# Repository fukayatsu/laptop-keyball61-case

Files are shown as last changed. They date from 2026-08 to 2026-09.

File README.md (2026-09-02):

# Keyball61 ラップボード

[Keyball61](https://shirogane-lab.net/)（左右ともトラックボール搭載）を膝上で使うための
3Dプリント製ラップボード。極力2mm厚の平面で構成し、キーボードは付属の
アクリル底板の代わりにプレートへ純正ネジで直接固定する。

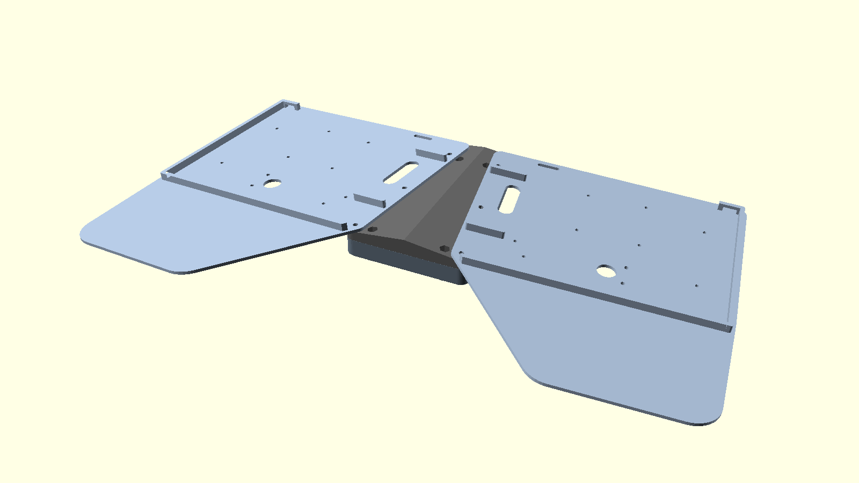
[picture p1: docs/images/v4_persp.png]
組立

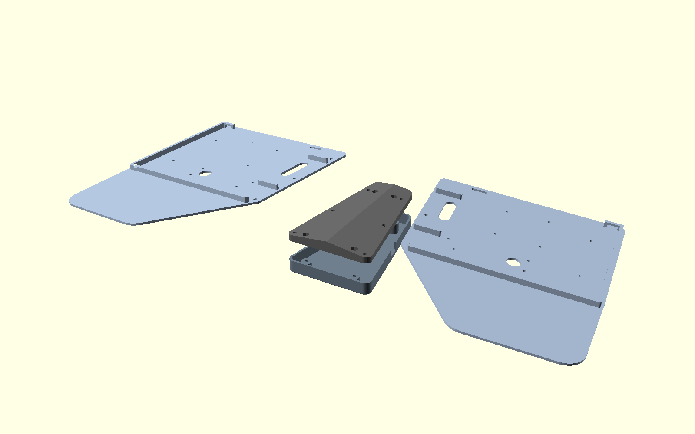
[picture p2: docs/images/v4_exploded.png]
分解


## 構成 (4パーツ + M3×8なべ×6 + M3×8皿×4 + M3ナット×10)

| パーツ | 印刷 | 説明 |
|---|---|---|
| `stl/v4_plate_left/right.stl` | ベタ置き | **一体平面プレート**(2mm): キーボード搭載部+パームレスト+中央張り出し。たわみ抑えのL字リブ(3×5mm)付き |
| `stl/v4_center_spine.stl` | ベタ置き | **切妻テント形の中実スパイン**: 上面=左右7°の切妻(テント角を作る)、底面=フラットで浮く。厚さ5.4〜11mm。底面は下面カバーの蓋を兼ねる |
| `stl/v4_center_cover.stl` | ベタ置き | **下面カバー**(任意): スパイン下の空間(深さ約10mm)を覆う。底2mm+スカート壁、外周はスパインと面一。底面の接地エッジと座ぐり口元は45°面取り(足に当たるため) |

- スプレイ10°・テンティング7°(スパインの形状が作る)・左右間隔は `v4_corner_x = 20`
- 全パーツ**組立の向きのままベタ置き印刷・サポートゼロ**
- **全ネジがボルト+ナット**(セルフタップなし):
  - ジョイント: プレート内縁がスパインに12mm重なり、上からM3×8なべ×3/側→
    スパイン底面の六角ポケットのナット(回り止め・天井は45°テーパーで印刷品質確保)
  - カバー: 下からM3×8皿×4(座ぐり奥の90°皿座=45°テーパーで印刷品質確保)→
    スパイン上面(露出帯)の六角井戸に落としたナット
- キーボードは従来のアクリルと同様、プレートに下から純正ネジで固定
- たわみ抑えリブ: ジェルパッド80×95mm領域(パーム外側の隅)の北縁+外側エッジの
  L字(パッドの位置決めストッパー兼用) + **スパイン接続帯の横リブ×2**(蝶番になる
  帯を曲げに直交する向きで補強)
- ケーブル関連: 外側後方の角に**ベルトループ**(上面のバー下にバンドを通す。
  貫通穴だとバンドが足に当たるため)、親指M2穴の真北に3×15貫通スロット、
  TRRSジャック真東にTRSケーブル通し穴10×33(プラグごと裏へ通しカバーのTRSノッチへ)、
  カバー北縁にUSBノッチ
- 注意: 平面構造なのでプレートは接地ライン(外側エッジ)以外浮く。膝上での使用前提

## 組立

1. スパイン底面の六角ポケット×6にM3ナットを差し込む
2. プレートをスパインの屋根フランジに重ね、上からM3×8なべ×3/側で締結
3. キーボードをプレートに載せ、下から純正ネジで固定(アクリル底板と同じ要領)。
   ボールケースも従来通り
4. (任意) スパイン上面の六角井戸×4にナットを落とし、カバーを下からM3×8皿×4で固定。
   ケーブル・Touch IDモジュール等はカバー内へ(バッテリー123mmは直置き不可)。
   Touch IDの固定は下の「Touch IDモジュール取付」を参照
5. ジェルパッドをリブに突き当てて貼る

## Touch IDモジュール取付 (任意)

カバー内に入れるTouch IDモジュールを固定する小物2点。

| パーツ | 印刷 | 説明 |
|---|---|---|
| `stl/touchid_plate.stl` | 底面をベッドに置く | **取付プレート**(15.6×16.0×1.05mm): 板厚0.9mm+天面中央にφ3×0.15mmのボス(モジュールの当たり面)。南辺にケーブル逃げの切欠き |
| `stl/touchid_foot.stl` | ベタ置き | **十字フット**(15.1×14.4×2.0mm): プレート裏の2mmスペーサ。プレートに接着する |

- 固定は**超低頭ネジ×4**。頭(φ2.72実測)がプレート裏に露出する構成なので、
  通し穴は「軸φ1.8が通り、かつ頭が座る」φ2.5にしてある。印刷で穴が細く出る前提の
  寸法で、頭が抜けるようなら `touchid_hole_d` を下げる
- **フットが十字なのはネジ頭を逃げるため**。単純な帯だと短辺6mmで倒れるので直交
  バーを足して支持スパンを 6.0 → 14.4mm に広げた。バー幅を決めているのはネジ穴
  ではなく裏に露出する頭で、穴中心から
  `touchid_head_d/2 + touchid_foot_head_clr` = 2.0mm を空けている
- 一体で出力しようとすると、天面を伏せれば中央ボス(0.15mm)だけが1層目になって
  プレート全面が宙に浮き、フット側を下にすればプレート四隅(ネジ座面)が
  無支持の張り出しになる。**2部品に分けて接着するのが正解**
- プレート天面のボスは0.15mmしかないので**積層0.15mm以下**で印刷すること

寸法は `scad/touchid/touchid_params.scad` に集約してある。

## ビルド

```sh
make            # 全STL生成 (要 OpenSCAD: brew install --cask openscad)
make v4         # ラップボード本体のみ
make touchid    # Touch ID取付部品のみ
make check      # 設計検証 (v4は要 pip install trimesh numpy)
make images     # ドキュメント画像の再生成
```

パラメータは `scad/params.scad`(共通)と `scad/v4/v4_params.scad`。
キーボード外形は公式アクリルDXFから `scripts/extract_outline.py` で生成した実寸
(`scad/keyball61_outline.scad`, ポイント単位 0.353407mm/unit)。

`make check` は2本の検証を回す。設計変更のたびに必ず実行すること。

- `scripts/verify_v4.py` (`make check-v4`): 単一ボディ/平面性/ネジ軸の素通し/
  ナット位置の空洞/印刷オーバーハング/部品間干渉
- `scripts/verify_touchid.py` (`make check-touchid`): ネジ穴が公称径で貫通しているか/
  ネジ頭の座面幅/フットがネジ頭を逃げているか/フットがプレート外形からはみ出して
  いないか/ベタ置きできる平面か。依存なし(標準ライブラリのみ)

`scad/touchid/` は本体(`scad/v4/`)とは独立していて、`scad/params.scad` の
`$fn` だけを共有する。

## 履歴

- v1(可動キャリッジ式)・v2(固定式の楔+ブリッジ+ブレース)・v3(中空モジュール5分割)は
  git履歴を参照。v4は前作ラップボードの平面構造方式を採用したもの

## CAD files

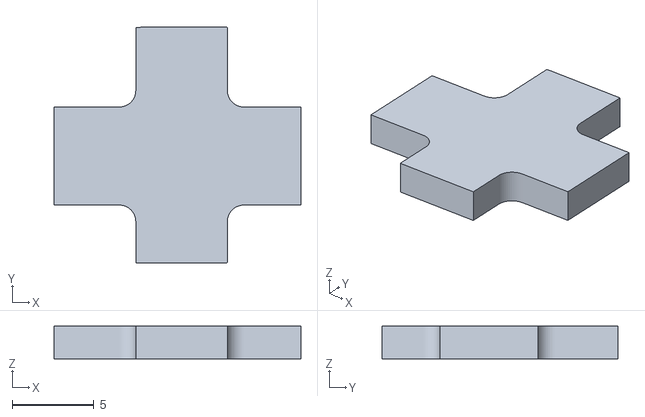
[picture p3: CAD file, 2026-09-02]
stl/touchid_foot.stl
15.1 x 14.4 x 2.00

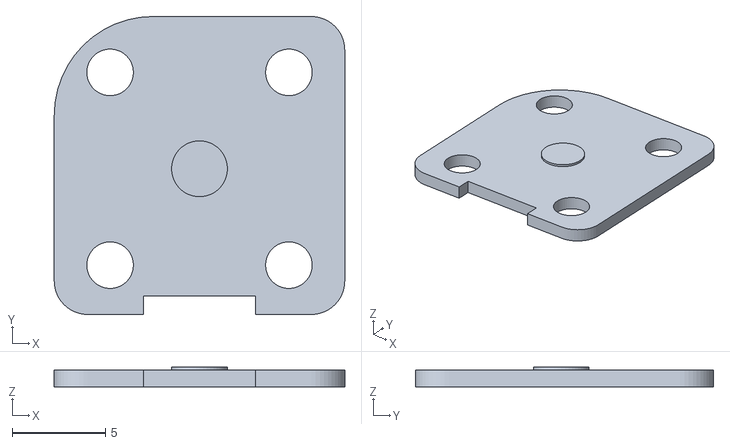
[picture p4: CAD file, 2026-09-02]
stl/touchid_plate.stl
15.6 x 16.0 x 1.05

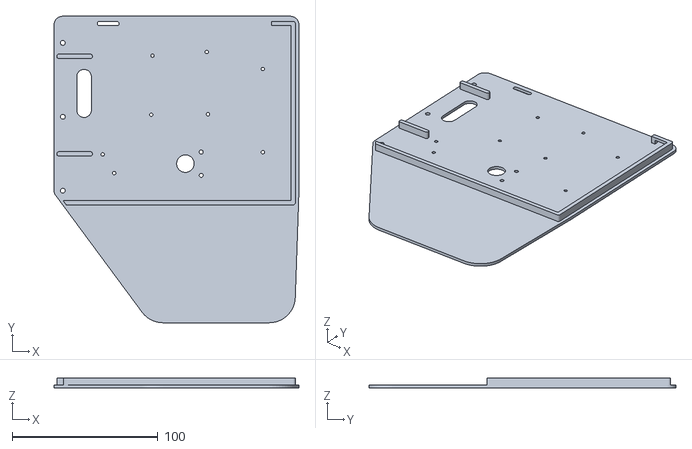
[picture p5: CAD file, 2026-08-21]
stl/v4_plate_right.stl
168.2 x 210.5 x 7.00

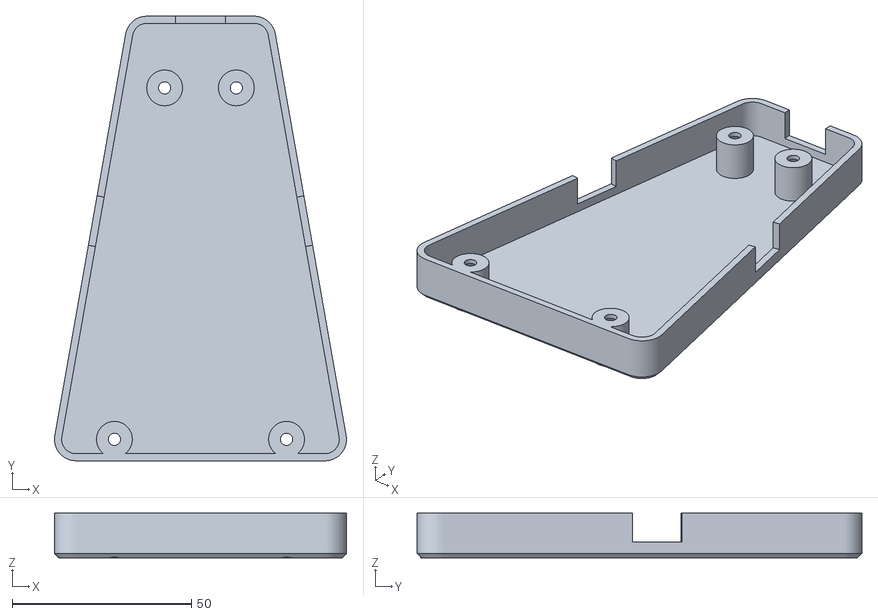
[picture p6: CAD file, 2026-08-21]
stl/v4_center_cover.stl
81.4 x 124.0 x 12.4

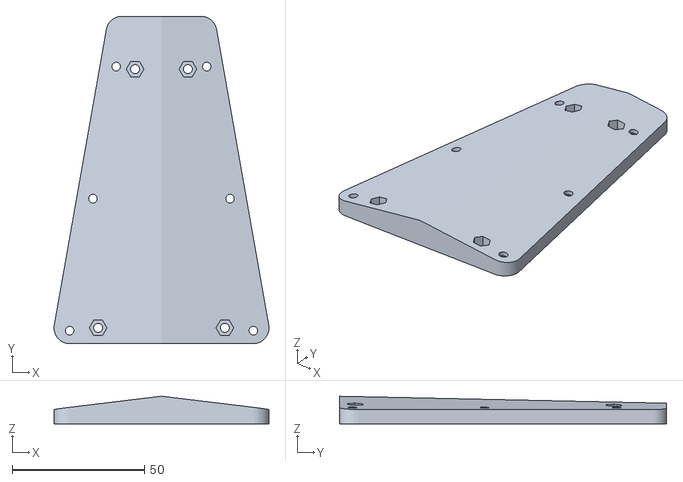
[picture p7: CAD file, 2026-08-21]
stl/v4_center_spine.stl
81.4 x 124.0 x 10.4

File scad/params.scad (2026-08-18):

// ============================================================
// Keyball61 ラップボード 共通パラメータ (v4で使用する項目のみ)
// 座標系: X+ = 右(東), Y+ = 奥(北), Z+ = 上
// 組立座標系(グローバル): 中心 x=0, 手前が y小
// 旧v2(固定式楔)・v3(中空モジュール)のパラメータはgit履歴を参照
// ============================================================

clr = 0.35;           // はめあいクリアランス(片側)

// ---------- 全体レイアウト ----------
splay        = 10;    // ハの字角(固定)。変更したら全パーツ再印刷
tent_angle   = 7;     // テンティング角(内側が高い)
kb_corner_x  = 45;    // キーボードブロック後内側コーナーの中心からの距離
                      // (v4は v4_corner_x = kb_corner_x - 25 を使用)
kb_corner_y  = 238;   // 同コーナーのY

// ---------- キーボード搭載部 ----------
kb_wall      = 6;     // アクリル外形の周囲マージン(外形の配置オフセット)
wedge_t0     = 6;     // 楔面の基準肉厚(lib.scadの傾斜面定義で使用)
plate_t      = 2;     // 取付プレート厚(=アクリル板厚。純正ネジ長がそのまま使える)
pocket_depth = 4.6;   // lib.scadの座面高さ定義で使用

// ---------- パームレスト ----------
palm_w       = 108;   // パームレスト幅
palm_x0      = 2.5;   // パームの外側エッジ位置(kbフレームx)
palm_d       = 88;    // 同奥行き
palm_overlap = 3;     // キーボードブロックへの食い込み
palm_r       = 18;    // 角R

// ---------- 穴径 ----------
ball_hole_d  = 12;    // ボール取出し穴(アクリルは11.3)
m2_hole_d  = 2.4;     // M2クリアランス(プレート側)
bc_hole_d  = 2.8;     // ボールケースネジ(プレート側, アクリルは2.36)

// M3 (ジョイント・カバー固定)
m3_hole_d  = 3.4;
m3_cs_d    = 6.8;     // 皿ざぐり径
m3_nut_af  = 5.8;     // 六角ナットポケット対辺(M3ナット5.5+0.3)
m3_nut_t   = 2.9;     // 同深さ

$fn = 48;

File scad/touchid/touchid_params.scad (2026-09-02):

// ============================================================
// Touch ID モジュール取付プレート + 十字フット のパラメータ
// 座標系: 上から見た形 / 原点=外形バウンディングボックスの南西角 / +Z=天面側
// 寸法はモジュール実物に合わせた実測値
// ============================================================

// ---------- プレート外形 ----------
touchid_plate_w = 15.6;   // 幅
touchid_plate_d = 16.0;   // 奥行き
touchid_plate_t = 0.9;    // 板厚(ネジ穴が貫通する厚み)
touchid_r_corner = 1.8;   // 南西・南東・北東の角R
touchid_r_nw     = 5.3;   // 北西の角R(ここだけ大きい)

// 南辺の切欠き(ケーブル逃げ)
touchid_notch_x  = [4.8, 10.8];
touchid_notch_d  = 1.0;

// ---------- ネジ穴 ----------
// 超低頭ネジ。軸φ1.8が通り、頭φ2.72がプレート裏に露出する
touchid_hole_d = 2.5;     // 通し穴。φ2.7では頭が座らず抜ける
touchid_head_d = 2.72;    // 頭径(実測)
touchid_hole_x = [3.0, 12.6];
touchid_hole_y = [2.65, 13.0];

// ---------- 天面のボス(モジュールの当たり面) ----------
touchid_boss_d = 3.0;
touchid_boss_h = 0.15;

// ---------- 十字フット ----------
touchid_foot_h        = 2.0;   // プレート裏に噛ませるスペーサ厚
touchid_foot_head_clr = 0.64;  // ネジ頭の外周からフットまでの逃げ
touchid_foot_fillet   = 1.0;   // 十字の内隅R(応力集中よけ)
touchid_foot_edge_clr = 0.3;   // Y方向バー端をプレート外形から控える量
touchid_foot_xbar     = [[0, 15.1], 3.0];  // [Xの範囲, ネジ列中心からの半幅]

// ---------- 導出 ----------
touchid_holes = [for (y = touchid_hole_y, x = touchid_hole_x) [x, y]];
touchid_hole_cx = (touchid_hole_x[0] + touchid_hole_x[1]) / 2;
touchid_hole_cy = (touchid_hole_y[0] + touchid_hole_y[1]) / 2;
// 穴中心から確保すべき逃げ半径(ネジ穴ではなく「裏に出る頭」で決まる)
touchid_head_r = touchid_head_d / 2 + touchid_foot_head_clr;

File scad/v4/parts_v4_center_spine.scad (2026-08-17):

include <v4_center_spine.scad>
// 底面(フラット)をベッドに置いて印刷。上面は7°の緩斜面でサポートゼロ
translate([0, 0, -v4_spine_z0]) v4_center_spine();

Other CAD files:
stl/v4_plate_left.stl
scad/v4/v4_center_spine.scad
scad/keyball61_outline.scad
scad/lib.scad
scad/touchid/parts_touchid_foot.scad
scad/touchid/parts_touchid_plate.scad
scad/touchid/touchid_foot.scad
scad/touchid/touchid_plate.scad
scad/v4/parts_v4_center_cover.scad
scad/v4/parts_v4_plate_left.scad
scad/v4/parts_v4_plate_right.scad
scad/v4/v4_assembly.scad
scad/v4/v4_center_cover.scad
scad/v4/v4_params.scad
scad/v4/v4_plate.scad

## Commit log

2026-08-14 固定式ラップボードv2の設計一式を追加
    - サイド2枚(取付面+パームレスト+7°楔+ハの字10°) + 中央ブリッジ + ブレースプレート + Touch IDポッド(バッテリー有無2種)の構成
    - ケースはアクリル底板の置き換え: 純正M2/ボールケースネジで直接固定(ネジ穴下は肉厚2.0mm)
    - 外形は公式DXF(3:1スケール)から実寸抽出(scripts/extract_outline.py)
    - 継手はリブ入り連続タブ(サイド凸/ブリッジ凹)、ブレースで閉断面化。全パーツサポート不要
    - ネジはM3x8皿×14+M3ナット×6に統一(KB固定は純正流用)
    - 旧・可動キャリッジ版は archive/adjustable-v1/ に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
    [assembly.scad, base.scad, brace.scad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]
2026-08-14 DXFスケールを実寸に修正し、H形ブレースを追加
    - 底板DXFのスケール誤りを修正: 3:1ではなくポイント単位(0.353407mm/unit)。
    公式KiCad基板(Right/Ball側)のスペーサー穴8点との相似変換フィット(残差0.002mm)で確定。
    プレート実寸 142.99x113.53mm (PCB Edge.Cuts 142.9x113.5 と一致)。全パーツ再生成
    - TRRSジャック位置を基板から実測 (グローバル ∓72, 181)
    - ブレースをH形に拡大 (155x130x3.5, y=100..230): TRSプラグ/ケーブル降下ゾーン
    (y168-212)を角丸切り欠きで回避しつつカバー面積を拡大。固定 M3x8皿 x3/側
    - パームレスト幅を150mmに戻す (kbブ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
    [brace.scad, brace.stl, bridge.stl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]
2026-08-14 パームレストの親指側をカットし印刷を安定化
    - パーム幅を150→108mm(外側基準 palm_x0=2.5)に絞り、親指側(内側前方)を開放
    - ブレース南帯の座面用に内側エッジ沿いへ幅14mmの支持アームを追加
    (ブリッジ/ブレースとの接合部は不変)
    - アーム〜パーム間はクロージングR22+オープニングR2で滑らかな輪郭に
    - ボールPCB逃げの矩形をプレート外形東端までに制限
    (内壁と継ぎ目帯を貫通してブレース中央帯ネジ座の材料を消していたバグを修正)
    [params.scad, side.scad, side_left.stl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]
2026-08-14 ブレースに親指キー回避の切り欠きを追加
    - 南ネジと中央ネジの間(y=114..147)のエッジを継ぎ目から12mm中央寄りに後退させ、
    キーボードの親指キークラスタの張り出しとの干渉を回避
    - TRS用の深い切り欠き(y=168..212)と中央ネジ(y=154)は維持。ネジ構成変更なし
    - 調整パラメータ: brace_thumb_y0/y1, brace_thumb_inset
    [brace.scad, brace.stl, params.scad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]
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2026-08-14 前方の逃げ範囲を調整し、ボールケースネジの座を確保
    - 実機のトラックボール部がプレートからはみ出すため、前方の縁の
    4mm掘り下げをボール周辺(プレートx=40)から東側に拡大
    (全幅までは不要のためボール周辺のみ。小指側の外周は元の高さ)
    - 外形線ぎわのボールケースネジ周囲Ø14は取付面レベルの座として残し、
    座ぐりの欠けを解消(掘り下げから保護しつつ取付面と同じ高さに彫る)
    [side.scad, side_left.stl, side_right.stl]
2026-08-15 ポッドのケーブル経路を整理
    - ベイ北壁にケーブル引き出しスリットを追加(幅12→15に拡大)
    - TRSケーブルギャラリーを廃止(スリットから北へ直接引き出す方式に)。
    ポッドは 64x94x8 / 64x132x11(電池版) に小型化
    - 充電ポート開口(南面)が壁を貫通していなかったのを修正し、
    さらに上開きのU字スロット化(庇0.5mmのブリッジを排除)。tid_port_h 廃止
    - トレイはブリッジ・サポート完全不要の形状に
    [params.scad, touchid_pod.scad, touchid_pod.stl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]
2026-08-16 キーボード固定をベッド直接印刷のマウントプレート方式に変更
    - 新パーツ mount_plate 左右各1 (143x114x2, アクリル底板相当):
    ベッドに平置き印刷して穴精度・平面・2mm厚を確保。キーボードとは
    純正M2/ボールケースネジで固定(楔内部の座ぐり奥の2mm薄肉は
    印刷精度が出ず固定に失敗したため=実印刷での知見)
    - サイド: ポケットを2mm深く(4.6)してプレートを収容。M2/BC位置は
    精度不要のΦ8貫通穴(ネジ頭逃げ+下からのドライバーアクセス)に置換
    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
    [brace.stl, bridge.stl, mount_plate.scad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]
2026-08-17 モジュラー構造v3(中空5分割・垂直ジョイント)を追加
    - KBフレーム(天板なしモノコック+米の字スポーク)、差し替え式パームシェル、
    中央トーションボックス+後付け底蓋の6パーツ構成。全パーツサポート不要
    - ジョイントは面一タブ+切り欠き+横挿しナットスロットの垂直M3x8なべx12
    (薄タブのため皿もみなし。スロット天井2.5mmでナット全ネジ掛かり)
    - パームタブは天板と完全面一(伏せ印刷で1層目から接地)、
    切り欠き床は楔面に沿わせて食い込みを回避
    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
    [parts_v3_center_box.scad, parts_v3_center_lid.scad, parts_v3_kb_box_left.scad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]
2026-08-17 v3を全面シンプル化: 井桁構造・長方形プレート・長耳・間隔5cm短縮
    初回印刷でネジ頭・スペーサーが内部構造と干渉した対策として再設計:
    - KBフレーム: 米の字スポーク+座リングを段付き周壁+井桁壁(x=44/113,
    y=45/74)に置換。内部構造は全キーボード穴から7mm以上離隔。
    ボール張り出し帯(x>=46)の逃げ(楔面-8.6)をv3にも実装
    - プレートをv3専用の長方形に(張り出し帯とパーム耳受けの上のみ欠き取り)。
    固定は井桁交点のΦ8ボス4箇所
    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
    [parts_v3_plate_left.scad, parts_v3_plate_right.scad, parts_v3_pod.scad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]
2026-08-17 v4平面構造を追加: 2mm一体プレート+切妻スパイン+下面カバー
    前作ラップボード方式の別系統。全パーツ組立の向きのままベタ置き印刷・
    サポートゼロ。
    - サイド = キーボード搭載部+パームレスト+中央張り出し一体の完全平面
    2mmプレート(キーボードフェンス6mmのみ立つ)。ボール張り出し帯の
    欠き取りは実物確認で不要と判明し既定OFF(-D v4_ball_relief=trueで復活)
    - 中央 = 切妻テント形の中実スパイン(上面=左右7°でテント角を作る、
    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
    [parts_v4_center_cover.scad, parts_v4_center_spine.scad, parts_v4_plate_left.scad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]
2026-08-17 v4プレートを完全な平板に: フェンス全廃・角にケーブルスロット追加
    - 北東フェンスがUSBポートと干渉(実機確認)→修正の流れでフェンス自体を
    全廃(位置決めはネジで足り、剛性は基板+スペーサーが担うため)。
    プレートは穴あきの完全な2mm平板になった
    - 外側後方の角(左サイドの左上/右サイドの右上)にケーブルまとめ用の
    3x15角丸スロットを追加(ストラップは穴と縁の間に通す)
    [v4_center_cover.stl, v4_center_spine.stl, v4_params.scad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]
2026-08-18 v4実機フィードバック反映: リブ追加・スロット調整・スパイン短縮
    - たわみ抑えリブ3x5mm x2本(実機使用でパーム側のたわみを指摘):
    ジェルパッド80x95領域の北縁に沿う水平1本+外側エッジ沿いの縦1本
    (西端で合流するL字。パッドのストッパー兼用)
    - ケーブルまとめ用3x15スロットを北縁沿いに2箇所へ:
    外側後方の角+親指キー付近の2つのM2穴の真北
    - スパイン/カバーをプレートが覆う範囲(y114-238)に短縮し、
    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
    [v4_center_cover.stl, v4_center_spine.stl, v4_params.scad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]
2026-08-18 v4: TRSケーブル通し穴を追加、リブ端部を整形
    - TRRSジャックの真東(外形東縁とスパイン西縁の間)に10x18の角丸通し穴。
    プラグごと表から裏へ通し、カバーのTRSノッチへ導く
    - リブ端部の整形: 縦リブと水平リブの始点を同一点にして面一で合流
    (0.5mmの角の出っ張りを解消)、水平リブ東端はクリップにかからない
    sx161で丸端に(斜め切れを解消)
    [v4_center_cover.stl, v4_center_spine.stl, v4_params.scad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]
2026-08-18 v4スパイン: 結束バンドスロット削除、ナットポケット天井を45°テーパーに
    - 結束バンドスロット(3x14x4対)は不要になったため削除
    - 六角ナットポケットの平天井はブリッジが垂れて綺麗に印刷できない
    (実機指摘)ため、六角d6.7->4の45°テーパーに変更。ナットは六角外周の
    リムで座るため締結力は不変。印刷オーバーハング 1.42 -> 0.3cm2
    [v4_center_cover.stl, v4_center_spine.scad, v4_center_spine.stl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]
2026-08-18 v4のセルフタップ全廃: カバー固定もボルト+ナットに
    - カバー取付をスパイン底面のΦ2.6下穴セルフタップから、スパイン上面
    (露出帯)の上開き六角井戸に落とし込んだナット+下からのM3x8なべに変更。
    井戸が回り止め・重力保持で工具は下のドライバーのみ
    - 南側ネジはジョイント六角ポケットを避けて(±10,120)->(±24,120)へ移動
    - v4のM3は全箇所ボルト+ナット(M3x8なべx10+ナットx10)に統一
    [v4_center_cover.stl, v4_center_spine.scad, v4_center_spine.stl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]
2026-08-18 v4のみ残してv1/v2/v3を削除
    - v2(固定式楔+ブリッジ+ブレース+ポッド)・v3(中空モジュール5分割)・
    archive/adjustable-v1(v1可動式)のソース/STL/検証スクリプト/画像を削除
    (旧版はgit履歴を参照)
    - params.scad をv4で使用する項目のみに整理(STLバイト一致で無変更を確認)
    - Makefile: make=v4ビルド / make check=verify_v4 / make images に簡素化
    - v4_assembly.scad(組立ビュー)と docs/images/v4_*.png を追加
    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
    [assembly.scad, base.scad, brace.scad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]
2026-08-19 v4カバー: 外周をスパインと一致、底面エッジ面取り、皿ネジ化
    - カバー外周をスパイン外形-1mmから完全一致(面一)に変更
    - 底面の接地外周エッジに45°x1.2面取り、座ぐり口元にも面取り
    (下面は足に当たるため)
    - カバー固定をM3x8皿x4に変更: 座ぐり奥を90°皿座(45°テーパー)にし、
    平天井の小ブリッジを解消(カバーのオーバーハング0.01cm2に)
    [v4_center_cover.scad, v4_center_cover.stl, v4_center_spine.stl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]
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2026-08-20 v4プレート: TRS穴延長・接続帯の横リブ・ベルトループ化(実機フィードバック)
    - TRSケーブル通し穴を北へ15mm延長(10x18 -> 10x33)
    - スパイン接続帯(外形東縁〜内縁の蝶番部)に曲げと直交する横リブx2
    (sy=31/98)を追加してたわみを抑制
    - 外側後方角の結束バンド穴を上面ベルトループ(バー下開口9x3)に変更:
    貫通穴だとバンドが足に当たるため。バンド/バックルは上面で完結
    [v4_center_cover.stl, v4_center_spine.stl, v4_params.scad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]
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2026-09-02 Touch IDモジュール取付: プレート+十字フットを追加
    カバー内のTouch IDモジュール固定用の小物2点。scad/touchid/ に本体(scad/v4/)
    とは独立して置き、共有するのは scad/params.scad の $fn のみ。
    - プレート(15.6x16.0x1.05): 板厚0.9+天面中央にφ3x0.15のボス。外形は角R1.8x3と
    北西R5.3の丸角矩形(半径違いの4円のhull)から南辺の切欠き6x1.0を引いたもの
    - ネジ穴φ2.5: 超低頭ネジの頭φ2.72(実測)がプレート裏に露出する構成のため、
    「軸φ1.8が通り、かつ頭が座る」径。座面は片側0.11mmで、印刷時に穴が細く
    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
    [parts_touchid_foot.scad, parts_touchid_plate.scad, touchid_foot.scad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]
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
